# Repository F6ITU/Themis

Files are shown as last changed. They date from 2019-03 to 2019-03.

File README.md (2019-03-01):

# Themis

A simple directional coupler

This coupler is based on a "tandem match" design with input compensation capacitor.
 
It should be able to fit any kind of amplifier, from 10 to 150 W

The pcb itself  supports the 2 main toroids of the transformer, input and output coax connectors 
and two coupled outputs.

These outputs are followed by a dual detector located on each branch of the coupler. The detected voltage 
is buffered by a dual rail to rail op amp. The output of the operational amplifier is then 
lowered by a resistive divider that keeps each output below the maximum input voltage of Angelia's ADC 

A optional "raw" FWD output is dedicated to the predistorsion -aka pure signal- feedback

3 different versions have been designed so far : V 1.0 was operational but the design and routing were absolutely ugly, with a crazy stripe-line trace.
V2.0 was a real enhancement of the general design (straight microstrip, simpler shielding). V2.1 offers now some small cleaning of the general design
(pure signal output located on the bottom layer, transformer junction also fixed on the bottom layer, thus enhancing the general insulation and 
offering a slightly better directivity. The attenuator of the P.S. output has a better access, thus simplifying the modification of it's value. 

V2.1 is the master branch since March 1st, 2019, and will stay "as is" as long as a new design is pushed.

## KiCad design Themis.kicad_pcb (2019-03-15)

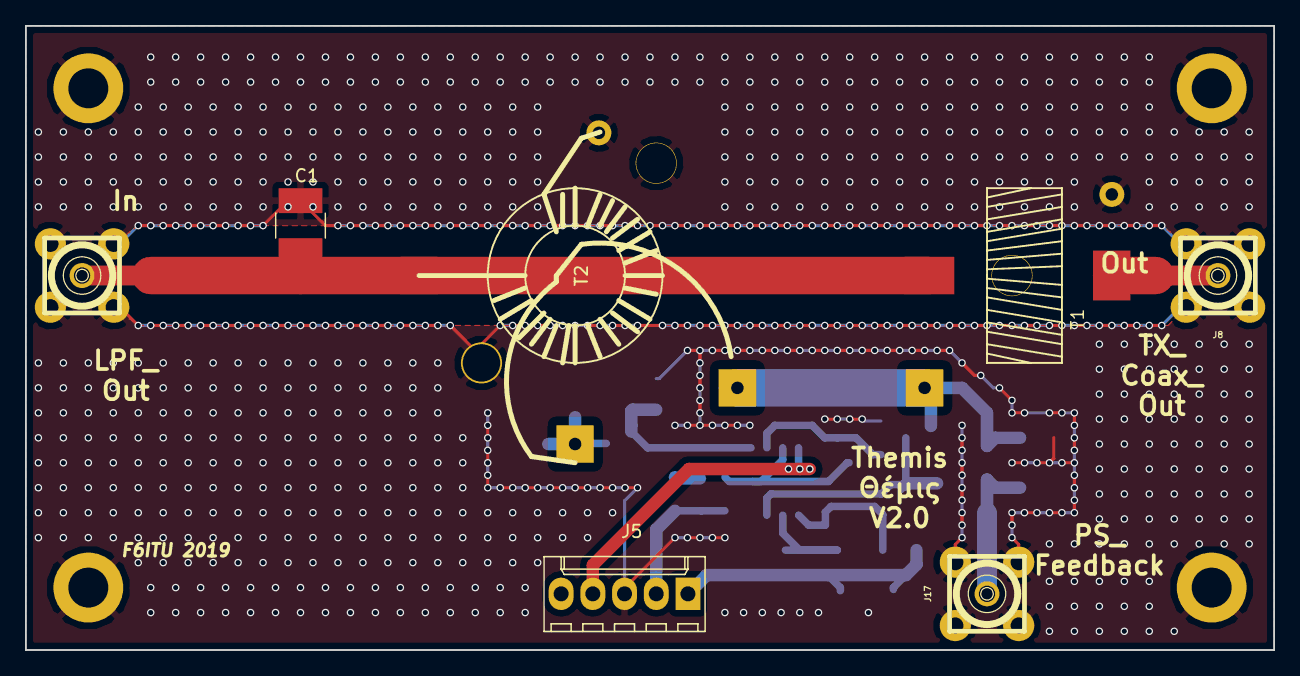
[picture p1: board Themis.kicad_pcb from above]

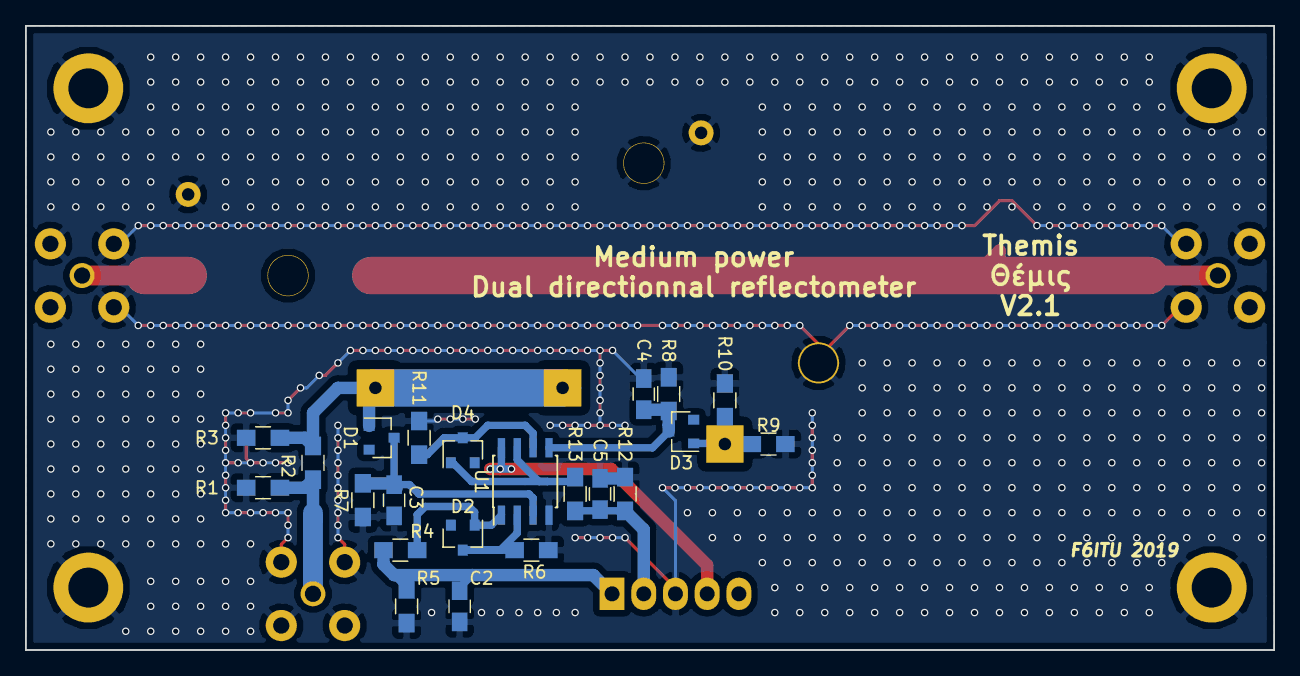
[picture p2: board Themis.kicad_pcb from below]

Board: 2 copper layers, 100.0 x 50.0 mm, 36 parts (22 on the bottom side), 15 nets.

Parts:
C1: 10p; ATC_500_HandSoldering
C2, C3, C4, C5: 10n; C_0805_HandSoldering
D1, D2, D3, D4: BAT54; D_SOT-23_ANK
J5: Conn_01x05; Molex_KK-6410-05_05x2.54mm_Straight
J7, J8, J17: SMA; SMA_PINS
J10, J11, J12, J13, J18, J18#2, J20: Conn_01x01; MountingHole_3.2mm_M3_DIN965_Pad
R1, R3: 53E; R_0805_HandSoldering
R2: 806E; R_0805_HandSoldering
R4, R13: 1k; R_0805_HandSoldering
R5, R12: 1K8; R_0805_HandSoldering
R6, R11: 220k; R_0805_HandSoldering
R7, R8: 100k; R_0805_HandSoldering
R9, R10: 100E; R_0805_HandSoldering
T1: Tr 1/33; TR_T50_V_smd
T2: Tr 33/1; TR_T50_H_SMD
U1: LMC6482; SOIC-8_3.9x4.9mm_P1.27mm

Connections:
+12V: J5.4, U1.8
GND: C1.1, C2.1, C3.2, C4.2, C5.1, J5.3, J7.2, J8.2, J10.1, J11.1, J12.1, J13.1, J17.2, J18#2.1, J20.1, R1.2, R3.2, R5.2, R6.2, R7.2, R8.2, R9.2, R10.2, R11.2, R12.2, T1.4, T2.2, U1.4
unnamed: C1.2, J7.1, T1.1, T2.1
unnamed: C2.2, J5.1, R4.1, R5.1
unnamed: C3.1, D1.1, R7.1, U1.3
unnamed: C4.1, D3.1, R8.1, U1.5
unnamed: C5.2, J5.2, R12.1, R13.1
unnamed: D1.2, R2.1, R3.1, T1.3, T2.3
unnamed: D2.1, R6.1, U1.2
unnamed: D2.2, R4.2, U1.1
unnamed: D3.2, R9.1, R10.1, T2.4
unnamed: D4.1, R11.1, U1.6
unnamed: D4.2, R13.2, U1.7
unnamed: J8.1, T1.2
unnamed: J17.1, R1.1, R2.2

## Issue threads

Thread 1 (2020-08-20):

metal case

ra1nb0w, 2020-08-20:
Hello,
thank you for sharing all projects!
I saw on electrolab's wiki that you put the board in a metal case; can you share which case you are using?
thank you

F6ITU, 2020-08-20:
Hi
Thanks for having a look at these designs :-)
all shieldings -Themis, Aion etc-  are home made 10x5 and 5x5 cm boxes, cut and formed by hand with a shear-brake

The closest Shubert box size is the item 55.5x111x40mm high,          ref 1000147 , but it will be a little bit oversised
see attachment below (I just used the lid to give you an idea)

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

Hope it will help
73'
Marc

ra1nb0w, 2020-08-20:
with long SMA the Shubert box can be useful. Thank you very much!

Closed 2020-08-20.

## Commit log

2018-01-04 first commit of Themis coupler
    [Themis.csv, Themis.kicad_pcb, Themis.sch]
2018-01-05 BAT54 and transformer shielding added
    [Themis.kicad_pcb, Themis.sch]
2018-01-05 via stitching added, new gerber
    [Themis-B.Cu.gbl, Themis-B.Mask.gbs, Themis-B.SilkS.gbo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]
2018-01-05 silkmask cleaning, new gerber
    [Themis-B.Cu.gbl, Themis-B.Mask.gbs, Themis-B.SilkS.gbo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]
2018-01-06 new stitching, new gerber
    [Themis-B.Cu.gbl, Themis-B.Mask.gbs, Themis-B.SilkS.gbo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]
2018-01-14 ajout ss rep
    [Themis.kicad_pcb, Themis.sch]
2018-01-21 new gerber added
    [Themis-B.Cu.gbl, Themis-B.Mask.gbs, Themis-B.SilkS.gbo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]
2018-01-22 BOM addded
    [Themis.csv]
2018-01-26 enlarged PS_Feedback trace
    [Themis-B.Cu.gbl, Themis-B.Mask.gbs, Themis-B.SilkS.gbo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]
2018-02-25 minor silk error fixed
    [Themis.kicad_pcb]
2018-03-10 relay references added
2018-07-15 temporary update
    [Themis.sch]
2018-07-15 en route pour la version 2.0
    [Themis.sch]
2018-07-19 preparing themis v2
    [Themis.kicad_pcb, Themis.sch]
2018-07-23 Themis V2
    [Themis.kicad_pcb, Themis.sch]
2018-07-23 Themis V2.0
    [Themis.csv]
2019-01-02 V3, work under progress, do not use as is
    [Themis.kicad_pcb]
2019-03-01 V 2.1, some components switched on the bottom side
    [Themis-2019-03-01-13-58-40.sch, Themis.kicad_pcb, _saved_Themis.sch]
2019-03-15 upgrade to Kicad 5.x
    [Themis-2019-03-12-22-23-55.sch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]
